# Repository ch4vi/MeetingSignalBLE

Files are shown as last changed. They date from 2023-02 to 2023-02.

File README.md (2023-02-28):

# Meeting Signal Bluethooh Low Energy




## Why

Currently I work from home 90% of the time, in this company I have lots of meetings using the camera and I use my headphones all the time ( we have two kids and sometimes the house gets very noisy) and sometimes my wife has to come in to get something from the room, I couple of times she got a bit embarrassed because my camera points to the door, I use the blur effect but she does not like it.

As an engineer I had to build an over complicated solution for a problem that could be resolved with a smart bulb. I started with a 3D model. It was simple, just a box with some holes and some M3 nuts. After that I grabbed an ESP32 that I already had and a led strip from a USB lamp that did not work because of some broken buttons (I bought them on a Flash Sale on Amazon and they did not last more than 2 months). My first idea was to connect the board to the MS Teams API to get my status and just turn the lights on or off depending on my status. While I found a project in which I could re-use [ESPTeamsPresence](https://github.com/toblum/ESPTeamsPresence), the company where I work doesn't allow my user to get its own [Presence](https://learn.microsoft.com/en-us/graph/api/presence-get?view=graph-rest-1.0&tabs=http) status. To solve this I had two options using the ESP32, use Bluetooth or Wifi. I don't have much experience developing on any of those with an ESP32 board. The Wifi option would be similar to the MS Teams API project, but I wanted to make my life harder and proceeded with the Bluetooth option.

## Hardware

- 3D printed models [Thingiverse]()
- ESP32 DEVKIT V1 [Aliexpress](https://www.aliexpress.com/w/wholesale-esp32-devkit-v1.html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)
- Switch
- TP4056 board [Aliexpress](https://www.aliexpress.com/item/1005004444047086.html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)
- 3.7V LiPo battery [Aliexpress](https://www.aliexpress.com/item/1005001310695209.html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)
- M3 nuts
- Some wires
- 5V LED strip [Aliexpress](https://www.aliexpress.com/item/1005004377378405.html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)
- 2x 100K resistors [Aliexpress](https://www.aliexpress.com/item/1005003117726705.html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)

\* *Links are provided as a guide, they are not affiliated links*<br />
** *I already had the ESP board, but if I had to buy a new one I would choose the USB-C version, but for the TP4056 I had the micro-USB version, and the 3D model is adapted to this model.*

## Instructions

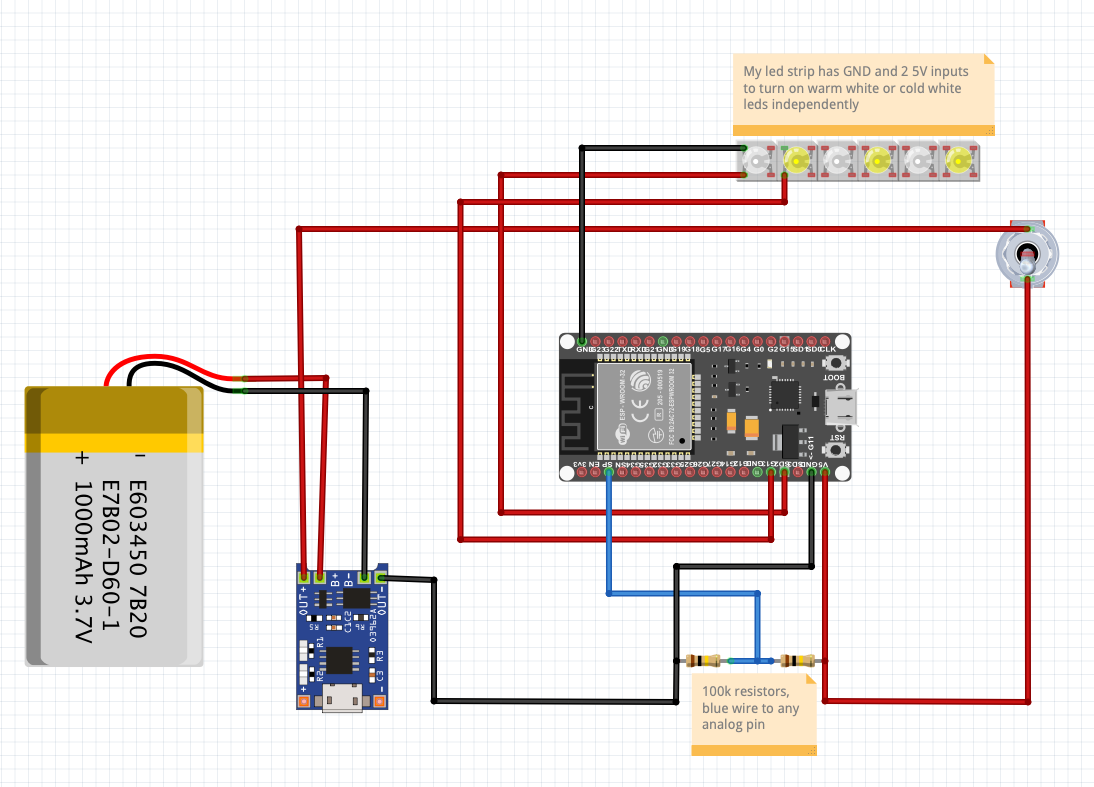
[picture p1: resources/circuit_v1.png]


### ESP32

Very straight forward, it has 2 characteristics, one to control the leds and the other the battery charge. In order to control the leds, the characteristic awaits an input string, **m** if it is to turn on the leds, or any other if it is to turn them off. The battery characteristic works as a notification characteristic, it notifies the battery level on every loop execution. There are some ESP32 boards that integrate battery level measurement. In my case, to get the battery level I followed this [approach](https://iotprojectsideas.com/esp8266-monitor-its-own-battery-level-using-iot/). It works but it is not very precise.

### Android

It needs a better clean-up, but it currently asks for permissions, connects to Bluetooth, and looks for a given MAC address. You have to change this parameter to connect to your device. You can get this address from the Bluetooth screen on your device. Maybe I will implement an additional screen to choose a device from a list (or maybe not ;D ). I have set the minimum SDK to 30 because my device is at this target. If you can, and you have some knowledge of Android development, you can upgrade this and remove some code. This is because currently the Bluetooth API is between 2 versions. There are some deprecations that I have to keep in order to work with my device. Check out this [post](https://punchthrough.com/android-ble-guide/) and their [project](https://github.com/PunchThrough/ble-starter-android) if you're interested in learning about Android Bluetooth API.

# Reference links:

* https://punchthrough.com/android-ble-guide/
* https://github.com/PunchThrough/ble-starter-android
* https://github.com/toblum/ESPTeamsPresence
* https://randomnerdtutorials.com/esp32-bluetooth-low-energy-ble-arduino-ide/
* https://github.com/kakopappa/bluetooth_android_esp32_example
* https://btprodspecificationrefs.blob.core.windows.net/assigned-numbers/Assigned%20Number%20Types/Assigned%20Numbers.pdf
* https://iotprojectsideas.com/esp8266-monitor-its-own-battery-level-using-iot/
* https://randomnerdtutorials.com/esp32-ble-server-client/#ESP32-BLE-Server
* https://docs.platformio.org/en/stable/tutorials/espressif32/arduino_debugging_unit_testing.html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

# LICENSE

    Meeting Signal BLE
    Copyright (C) 2023  Xavi Anyo

    This program is free software: you can redistribute it and/or modify
    it under the terms of the GNU General Public License as published by
    the Free Software Foundation, version 3 of the License, or any later 
    version.

    This program is distributed in the hope that it will be useful,
    but WITHOUT ANY WARRANTY; without even the implied warranty of
    MERCHANTABILITY or FITNESS FOR A PARTICULAR PURPOSE.  See the
    GNU General Public License for more details.

    You should have received a copy of the GNU General Public License
    along with this program.  If not, see <http://www.gnu.org/licenses/>.

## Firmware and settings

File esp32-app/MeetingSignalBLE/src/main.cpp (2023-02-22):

#include <Arduino.h>
#include <BLEDevice.h>
#include <BLEServer.h>
#include <BLEUtils.h>
#include <BLE2902.h>

BLEServer *pServer = NULL;
bool deviceConnected = false;
bool oldDeviceConnected = false;

// See the following for generating UUIDs:
// https://www.uuidgenerator.net/
#define SERVICE_UUID "e0387cb2-42b1-42dd-850d-a8d068ee7047"
#define MEETING_CHARACTERISTIC_UUID BLEUUID((uint16_t)0x2AE2)
#define BATTERY_CHARACTERISTIC_UUID BLEUUID((uint16_t)0x2A19)
#define CCC_DESCRIPTOR_UUID BLEUUID((uint16_t)0x2902)

BLECharacteristic meetingStateCharacterisitic(
    MEETING_CHARACTERISTIC_UUID,
    BLECharacteristic::PROPERTY_READ |
        BLECharacteristic::PROPERTY_WRITE |
        BLECharacteristic::PROPERTY_NOTIFY);
BLEDescriptor meetingStateDescriptor(CCC_DESCRIPTOR_UUID);

BLECharacteristic batteryLevelCharacterisitic(BATTERY_CHARACTERISTIC_UUID, BLECharacteristic::PROPERTY_READ | BLECharacteristic::PROPERTY_NOTIFY);
BLEDescriptor batteryLevelDescriptor(CCC_DESCRIPTOR_UUID);

// LED parameters
#define LED_ON "m"
#define LED_OFF "x"
String led_currentState = LED_OFF;

const uint8_t PIN_WARM = 14; // corresponds to GPIO14
const uint8_t PIN_COLD = 12; // corresponds to GPIO12
#define LED_WARM PIN_WARM
#define LED_COLD PIN_COLD

// Battery parameters
float batt_level = 0;

const uint8_t ANALOG_BATT = 36; // 13 corresponds to GPIO36 ADC1_CH0
#define INPUT_BATT ANALOG_BATT
float batt_calibration = 0.52; // Check Battery voltage using multimeter (multimeterRead - float_voltage) check getBatteryLevel()

/*
 * LED control functions
 */

void waitingStatusAlert()
{
  Serial.println("waiting status");

  digitalWrite(LED_COLD, HIGH);
  delay(2000);
  digitalWrite(LED_WARM, HIGH);
  delay(2000);

  digitalWrite(LED_COLD, LOW);
  delay(2000);
  digitalWrite(LED_WARM, LOW);
  delay(2000);
}

void connectedAlert()
{
  Serial.println("connection successful");

  for (size_t i = 0; i < 4; i++)
  {
    digitalWrite(LED_COLD, HIGH);
    digitalWrite(LED_WARM, HIGH);
    delay(1000);

    digitalWrite(LED_COLD, LOW);
    digitalWrite(LED_WARM, LOW);
    delay(1000);
  }
}

void disconnectedAlert()
{
  Serial.println("disconnected successful");

  for (size_t i = 0; i < 4; i++)
  {
    digitalWrite(LED_COLD, HIGH);
    digitalWrite(LED_WARM, HIGH);
    delay(1000);

    digitalWrite(LED_COLD, LOW);
    digitalWrite(LED_WARM, LOW);
    delay(1000);
  }
}

void changeLedState(String state)
{
  if (led_currentState.equals(state))
  {
    return;
  }
  else if (state.equals(LED_ON))
  {
    digitalWrite(LED_COLD, HIGH);
    digitalWrite(LED_WARM, HIGH);
  }
  else
  {
    digitalWrite(LED_COLD, LOW);
    digitalWrite(LED_WARM, LOW);
  }
  led_currentState = state;
}

/*
 * BATTERY control functions
 */

float mapfloat(float x, float in_min, float in_max, float out_min, float out_max)
{
  return (x - in_min) * (out_max - out_min) / (in_max - in_min) + out_min;
}

int getBatteryLevel(int analogValue)
{

  // divide by 4095 because analog read range in ESP32 is up to 4095
  // multiply by two as voltage divider network is 100K & 100K Resistor
  float voltage = (((analogValue * 3.3) / 4095) * 2 + batt_calibration);

  // 2.8V as Battery Cut off Voltage & 4.2V as Maximum Voltage
  int bat_percentage = mapfloat(voltage, 2.8, 4.2, 0, 100);

  if (bat_percentage >= 100)
  {
    bat_percentage = 100;
  }

  if (bat_percentage <= 0)
  {
    bat_percentage = 0;
  }

  Serial.println("===BATTERY===");
  Serial.print("Read = ");
  Serial.println(analogValue);
  Serial.print("Output Voltage = ");
  Serial.println(voltage);
  Serial.print("Battery Percentage = ");
  Serial.println(bat_percentage);

  return bat_percentage;
}

/*
 * BLUETOOTH Callbacks
 */

class MyServerCallbacks : public BLEServerCallbacks
{
  void onConnect(BLEServer *pServer)
  {
    deviceConnected = true;
  };

  void onDisconnect(BLEServer *pServer)
  {
    deviceConnected = false;
  }
};

class MyCallbacks : public BLECharacteristicCallbacks
{
  void onWrite(BLECharacteristic *pCharacteristic)
  {
    std::string rxValue = pCharacteristic->getValue();

    if (rxValue.length() > 0)
    {

      String inputMessage = rxValue.c_str();
      if (inputMessage.equals(LED_ON))
      {
        changeLedState(LED_ON);
      }
      else
      {
        changeLedState(LED_OFF);
      }

      Serial.println("*********");
      Serial.print("Received raw Value: ");
      Serial.println(inputMessage);
      Serial.println("*********");
    }
  }
};

/*
 * MAIN
 */

void setup()
{
#if defined(DEBUG)
  Serial.begin(115200);
#endif

  // Setup led control
  pinMode(LED_COLD, OUTPUT);
  pinMode(LED_WARM, OUTPUT);

  // Create the BLE Device
  BLEDevice::init("MeetingSignal");

  // Create the BLE Server
  pServer = BLEDevice::createServer();
  pServer->setCallbacks(new MyServerCallbacks());

  // Create the BLE Service
  BLEService *pService = pServer->createService(SERVICE_UUID);

  // Meeting state characteristic
  pService->addCharacteristic(&meetingStateCharacterisitic);
  meetingStateDescriptor.setValue("BLE Led state");
  meetingStateCharacterisitic.setCallbacks(new MyCallbacks());
  meetingStateCharacterisitic.addDescriptor(&meetingStateDescriptor);

  // Battery level characteristic
  pService->addCharacteristic(&batteryLevelCharacterisitic);
  batteryLevelDescriptor.setValue("BLE Battery level");
  batteryLevelCharacterisitic.addDescriptor(&batteryLevelDescriptor);

  // Start the service
  pService->start();

  // Start advertising
  BLEAdvertising *pAdvertising = BLEDevice::getAdvertising();
  pAdvertising->addServiceUUID(SERVICE_UUID);
  pAdvertising->setScanResponse(true);
  pAdvertising->setMinPreferred(0x12);
  BLEDevice::startAdvertising();
  Serial.println("Waiting a client connection to notify...");
}

void loop()
{
  // connected
  if (deviceConnected)
  {
    Serial.println("send bluetooth...");

    meetingStateCharacterisitic.setValue(led_currentState.c_str());
    meetingStateCharacterisitic.notify();

    delay(2000);

    int analogValue = analogRead(INPUT_BATT);
    batt_level = getBatteryLevel(analogValue);
    static char battByte[6];
    dtostrf(batt_level, 6, 2, battByte);
    Serial.println(battByte);

    batteryLevelCharacterisitic.setValue(battByte);
    batteryLevelCharacterisitic.notify();

    delay(2000); // bluetooth stack will go into congestion, if too many packets are sent
  }

  // disconnecting
  if (!deviceConnected && oldDeviceConnected)
  {
    delay(500);                    // give the bluetooth stack the chance to get things ready
    BLEDevice::startAdvertising(); // restart advertising
    Serial.println("start advertising");
    oldDeviceConnected = deviceConnected;
    disconnectedAlert();
  }

  // connecting
  if (deviceConnected && !oldDeviceConnected)
  {
    oldDeviceConnected = deviceConnected;
    connectedAlert();
  }

  // advertising
  if (!deviceConnected && !oldDeviceConnected)
  {
    waitingStatusAlert();
  }
}

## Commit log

2023-02-15 Added platform.io esp32 project
2023-02-21 esp32: clean up and minor fixes
    [main.cpp]
2023-02-22 Added Material 3 theme
2023-02-27 Updae README
    [MeetingSignal.fzz]
